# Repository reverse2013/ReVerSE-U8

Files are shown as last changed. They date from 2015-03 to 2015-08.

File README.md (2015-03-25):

# ReVerSE-U8
Development Kit

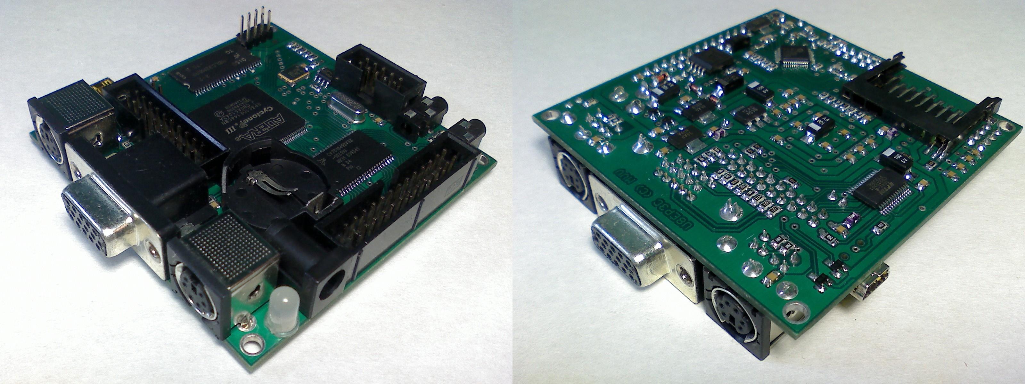
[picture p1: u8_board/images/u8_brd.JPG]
 
Платформа ориентированна на создание SoC систем на микросхеме программируемой логики ПЛИС. Отлично подходит для домашнего обучения и позволяет полностью воссоздать множество ретро-компьютеров.

Схема реализуемого устройства задается прошивкой, записываемой в статическую память микросхемы ПЛИС. Микросхема ПЛИС представляет собой массив логических элементов, таким образом, существует возможность исправления ошибок схемы, а также добавления новых устройств, с помощью перепрошивки ПЛИС (выполняемой средствами самого устройства, либо через USB-кабель). 

Системы-на-кристалле потребляют меньше энергии, стоят дешевле и работают надёжнее, чем наборы микросхем с той же функциональностью. В отличие от обычных цифровых микросхем, логика работы ПЛИС не определяется при изготовлении, а задаётся посредством программирования (проектирования).

Для программирования используются программаторы и отладочные среды, позволяющие задать желаемую структуру цифрового устройства в виде принципиальной электрической схемы или программы на специальных языках описания аппаратуры: Verilog, VHDL, AHDL и др. В конфигурации ПЛИС реализуются почти все компоненты компьютера. Вне ПЛИС находятся только оперативная память, аппаратные интерфейсы для подключения клавиатуры, мыши, монитора, и других устройств.

#### Спецификация:
- FPGA Altera EP3C10E144C8N (supports Cyclone III EP3C5)
- SDRAM 32MB x 8 bit (supports 8 MB/16 MB/32 MB x 8 bit)
- SRAM 512KB х 8 bit (supports 1024 КB)
- SPI FLASH 4 Mb (supports 1/4/16/64 Mb)
- Audio Codec VS1053b Ogg Vorbis/MP3/AAC/WMA/FLAC/MIDI 
- RTC PCF8583 + CR2032
- VGA 15-pin RGB(3:3:3)
- SD cart
- Connector 20-pin
- Connector 26-pin
- Connector 8-pin
- Audio in 3.5 mm 
- Audio out 3.5 mm
- miniUSB (USB-UART & CBUS-JTAG)
- JTAG (CBUS-JTAG)
- PS/2 keyboard/mouse
- PS/2 moude/keyboard
- Power DC +5V 500 mA
- PCB Size 75 х 75 mm

#### Вид платы:
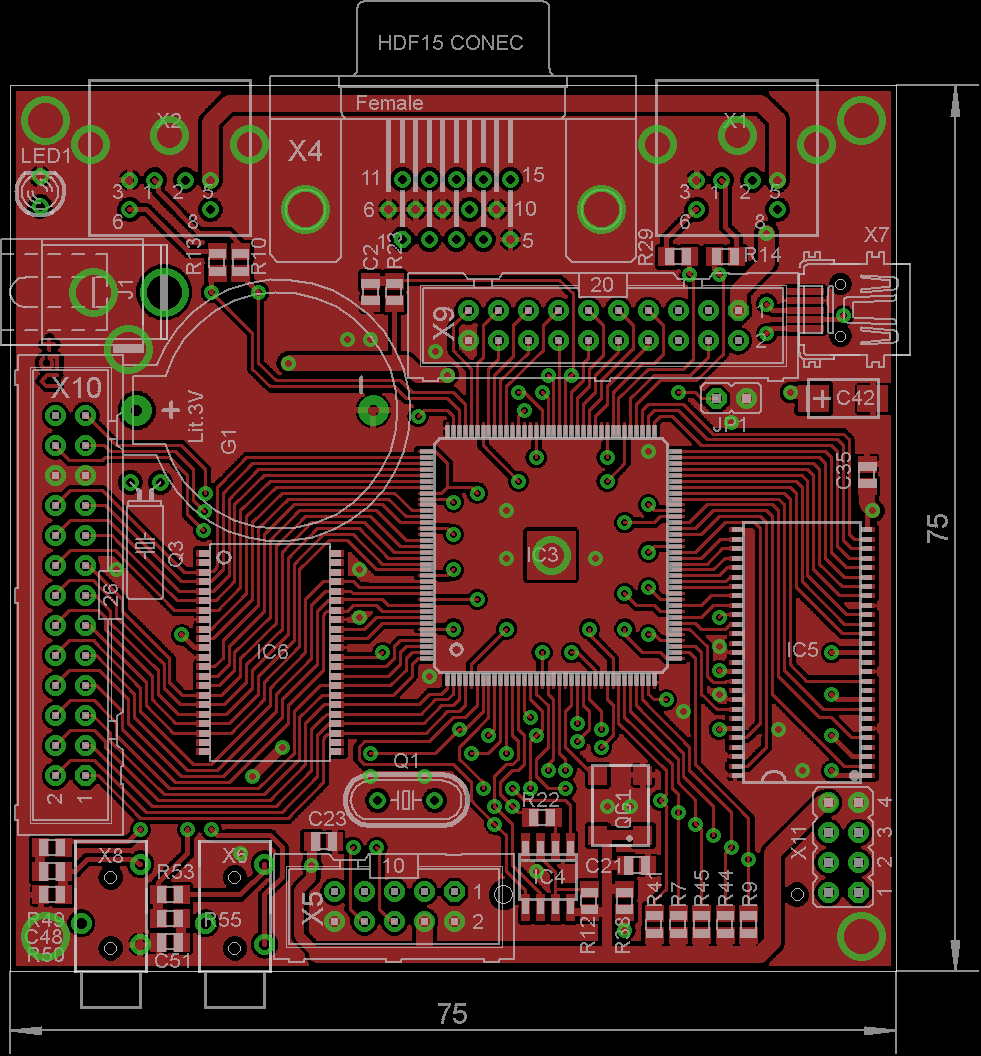
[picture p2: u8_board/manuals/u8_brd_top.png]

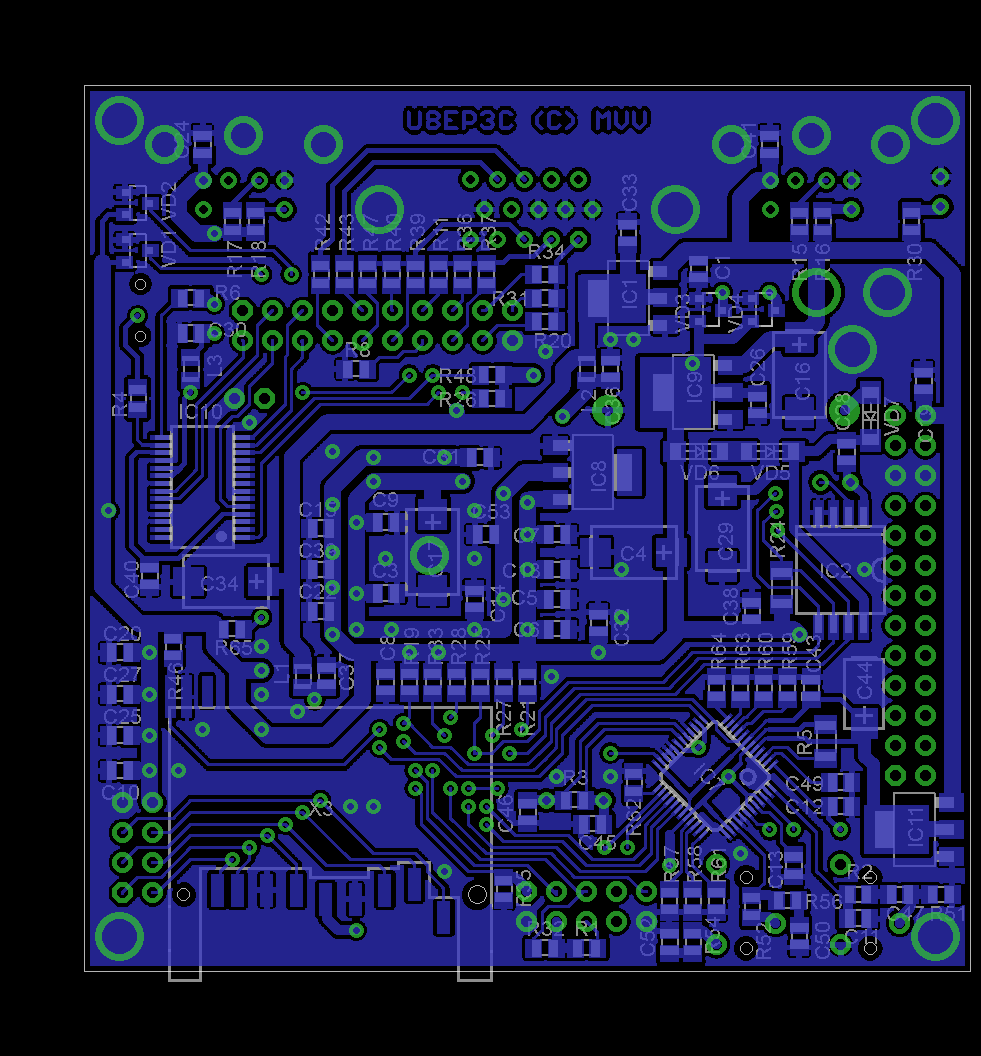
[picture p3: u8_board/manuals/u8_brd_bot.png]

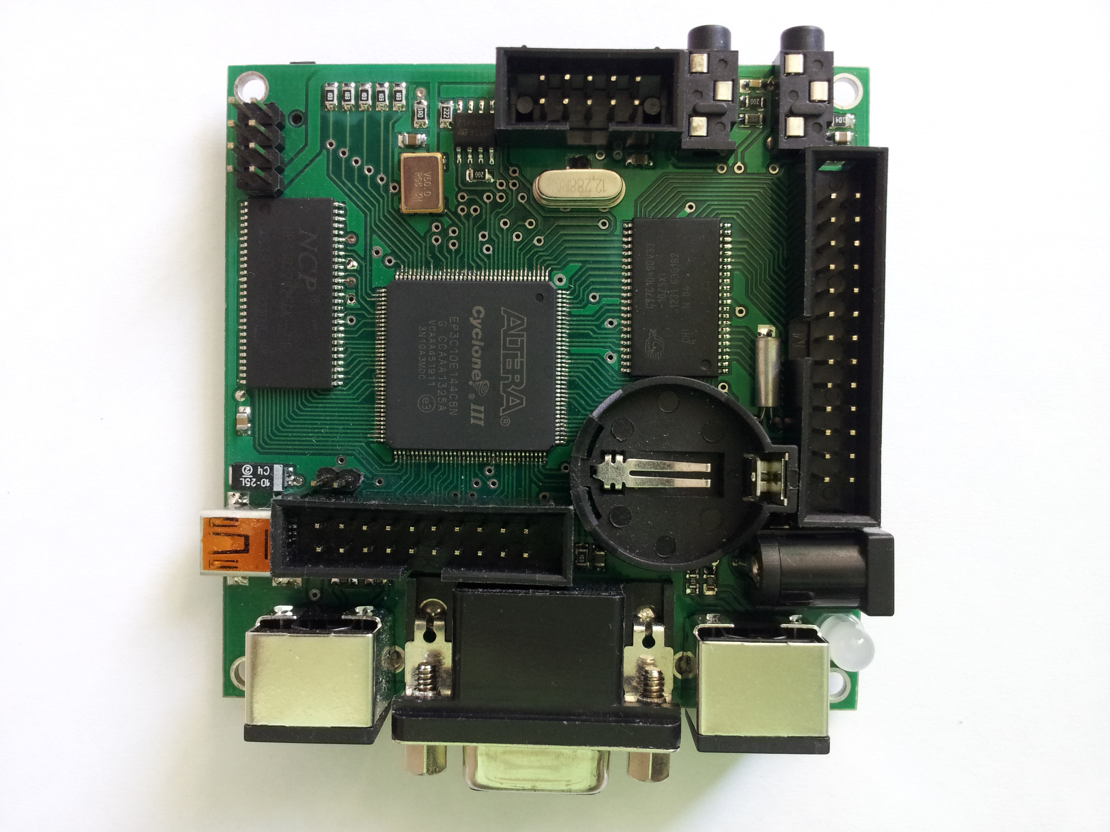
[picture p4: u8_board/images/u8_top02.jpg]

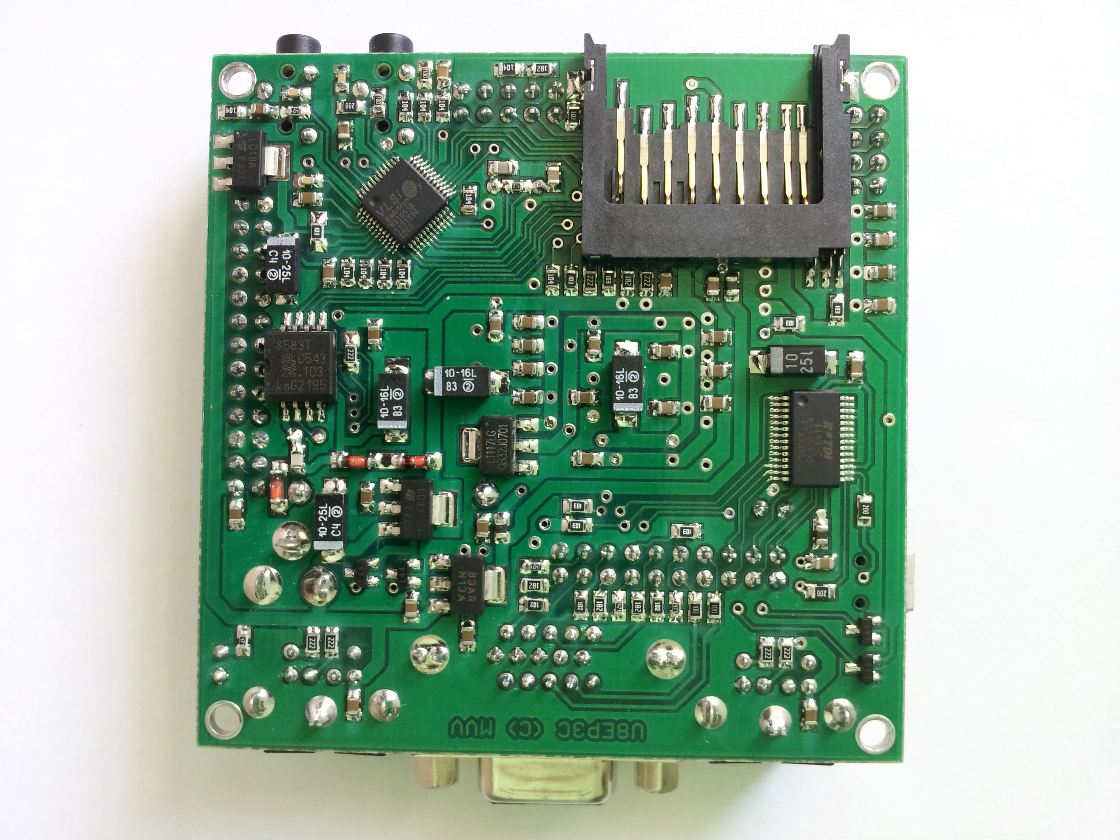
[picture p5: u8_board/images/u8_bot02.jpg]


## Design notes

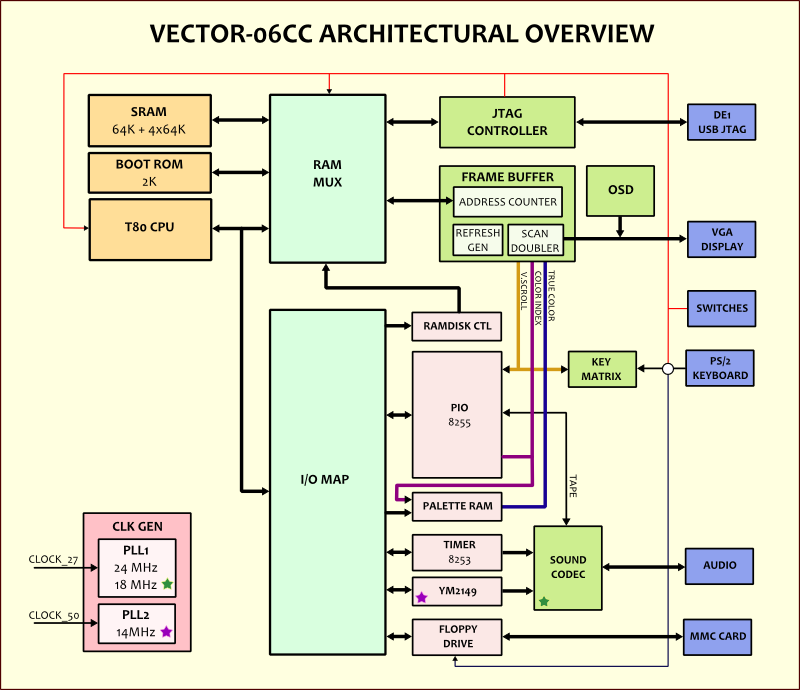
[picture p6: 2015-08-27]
u8_vector/doc/computer.png

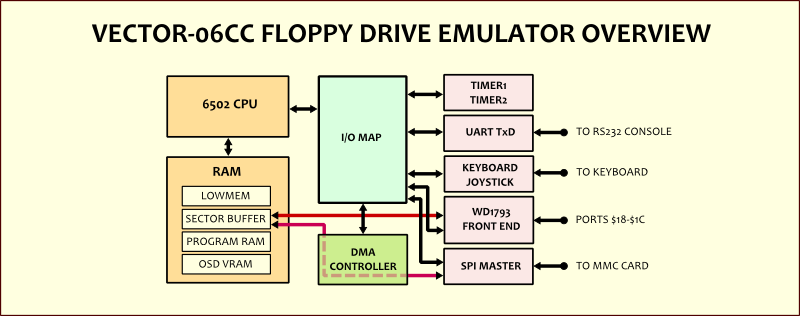
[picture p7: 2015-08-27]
u8_vector/doc/floppy.png

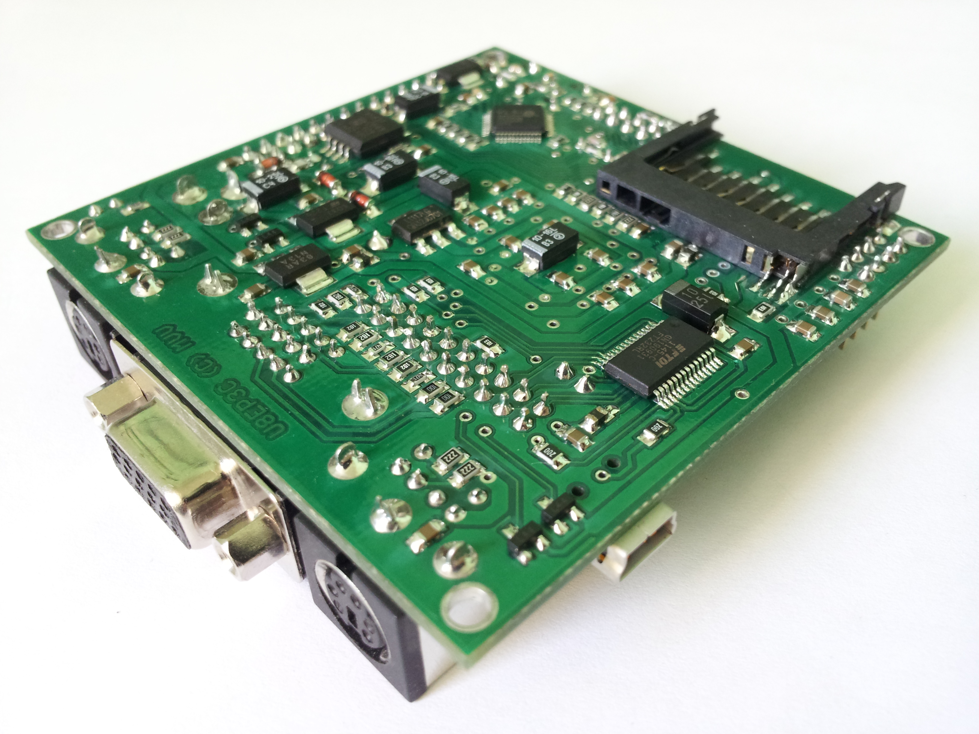
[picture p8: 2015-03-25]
u8_board/images/u8_bot01.jpg

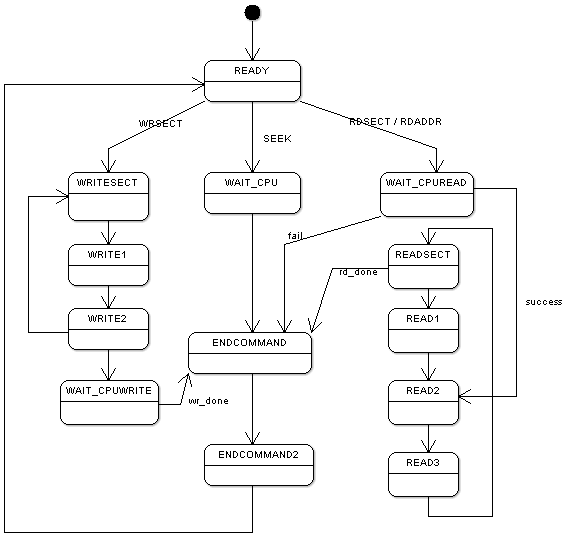
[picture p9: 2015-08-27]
u8_vector/doc/wd_statemachine.png

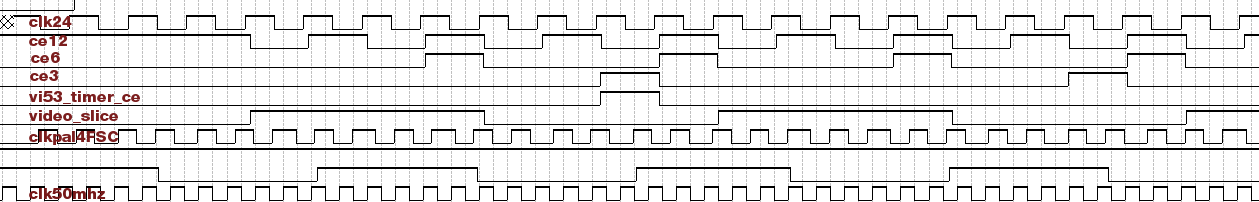
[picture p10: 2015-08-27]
u8_vector/doc/clocks-2.png

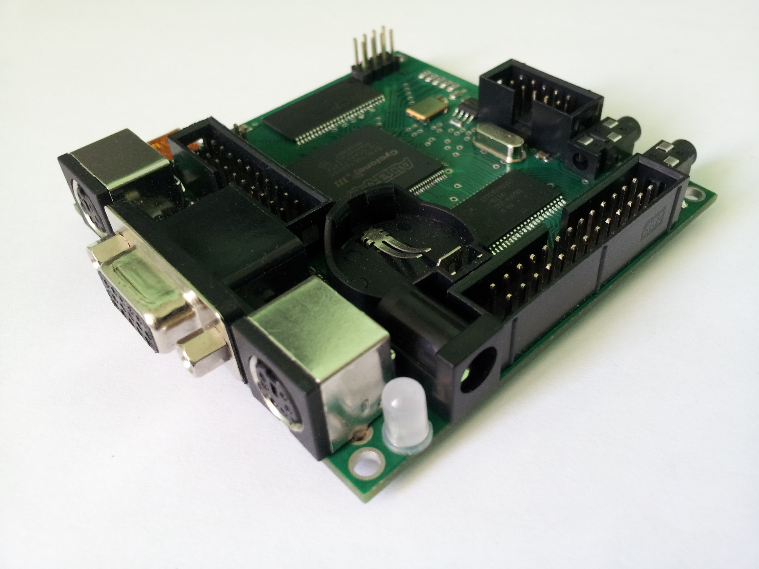
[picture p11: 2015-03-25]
u8_board/images/u8_top01.jpg

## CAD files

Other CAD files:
u8_speccy/boards/reverse_u9/syn/stp1.stp

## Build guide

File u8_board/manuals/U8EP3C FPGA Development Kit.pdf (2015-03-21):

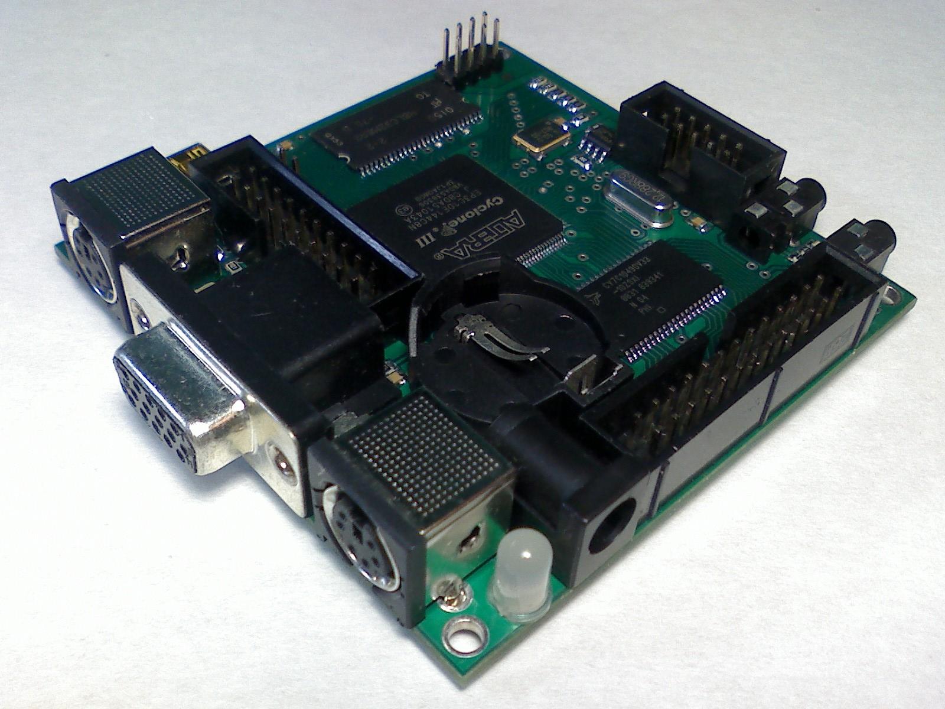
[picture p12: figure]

# U8EP3CFPGA Development Kit

# User Manual

## U8EP3C User Manual

# 1.1 Layout and Components

This chapter presents the features and design characteristics of the U8EP3C board.

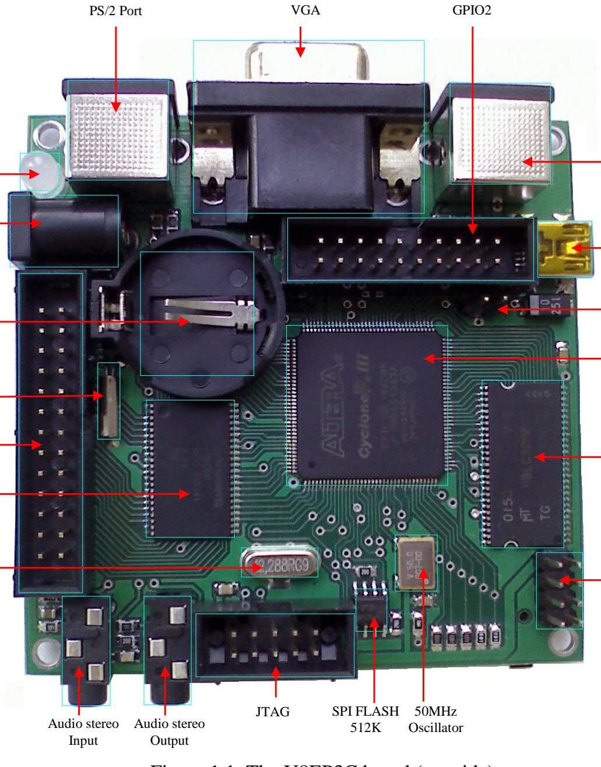
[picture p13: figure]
PS/2 Port; VGA; Audio stereo Input; JTAG; SPI FLASH; 50MHz Oscillator; GPIO2; Audio stereo Output

## Figure 1.1. The U8EP3C board (top side)

## A photograph of the U8EP3C board is shown in Figure 1.1-1.2. It depicts the layout of the

board and indicates the location of the connectors and key components.

## The following hardware is provided on the U8EP3C board:

## Altera Cyclone® III 3C10 FPGA device

## Altera Serial Configuration device – 512-Kbyte SPI Flash memory M25P40 (EPCS4)

## JTAG for programming and user API control; both and Active Serial (AS) programming

## modes are supported

## 32-Mbyte 8-bits SDRAM

## 512-Kbyte 8-bits SRAM memory

## SD Card socket

USB-UART

Power Led

Power Supply
5V DC

Reset/GPI
Battery CR2032

Oscillator
32.768KHz

SRAM
512K x 8 bit

GPIO3

SDRAM
32M x 8 bit

Cyclone III
EP3C10

PS/2 Port

Oscillator
12.288MHz

GPIO1

## 1 red power LED

## 50-MHz oscillator for clock sources

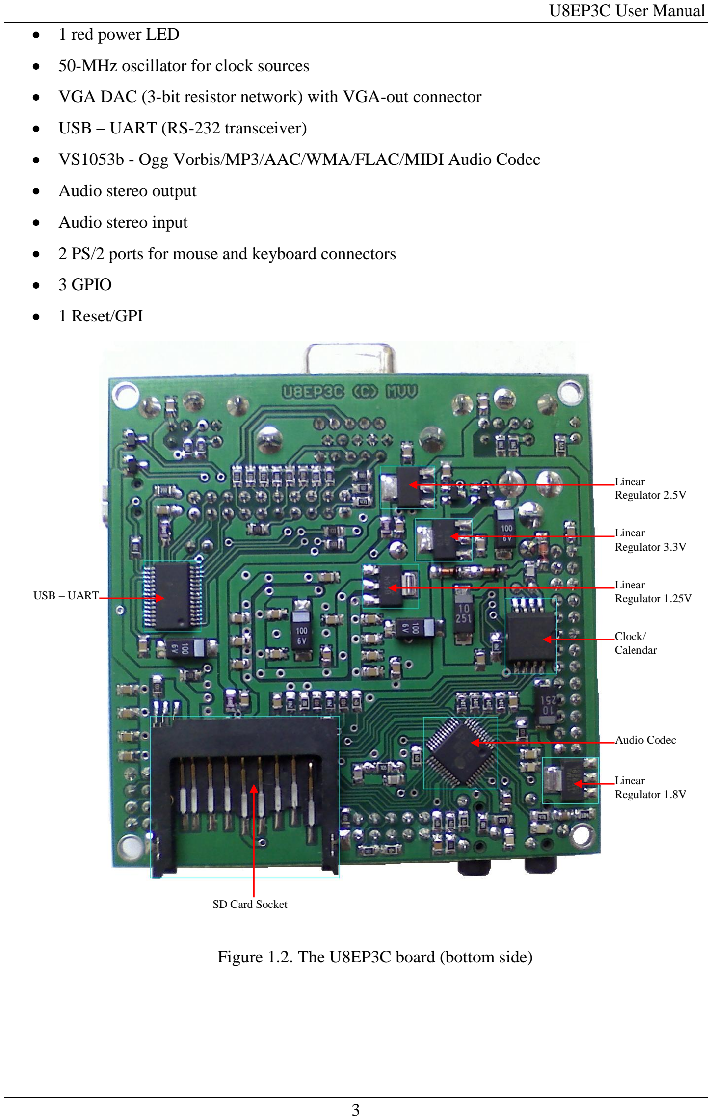
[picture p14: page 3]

## VGA DAC (3-bit resistor network) with VGA-out connector

## USB – UART (RS-232 transceiver)

## VS1053b - Ogg Vorbis/MP3/AAC/WMA/FLAC/MIDI Audio Codec

## Audio stereo output

## Audio stereo input

## 2 PS/2 ports for mouse and keyboard connectors

## 3 GPIO

## 1 Reset/GPI

## Figure 1.2. The U8EP3C board (bottom side)

USB – UART

Linear
Regulator 2.5V

Linear
Regulator 3.3V

Linear
Regulator 1.25V

SD Card Socket

Audio Codec

Clock/
Calendar

Linear
Regulator 1.8V

# Appendix 2.1 ByteBlasterMV Schematic

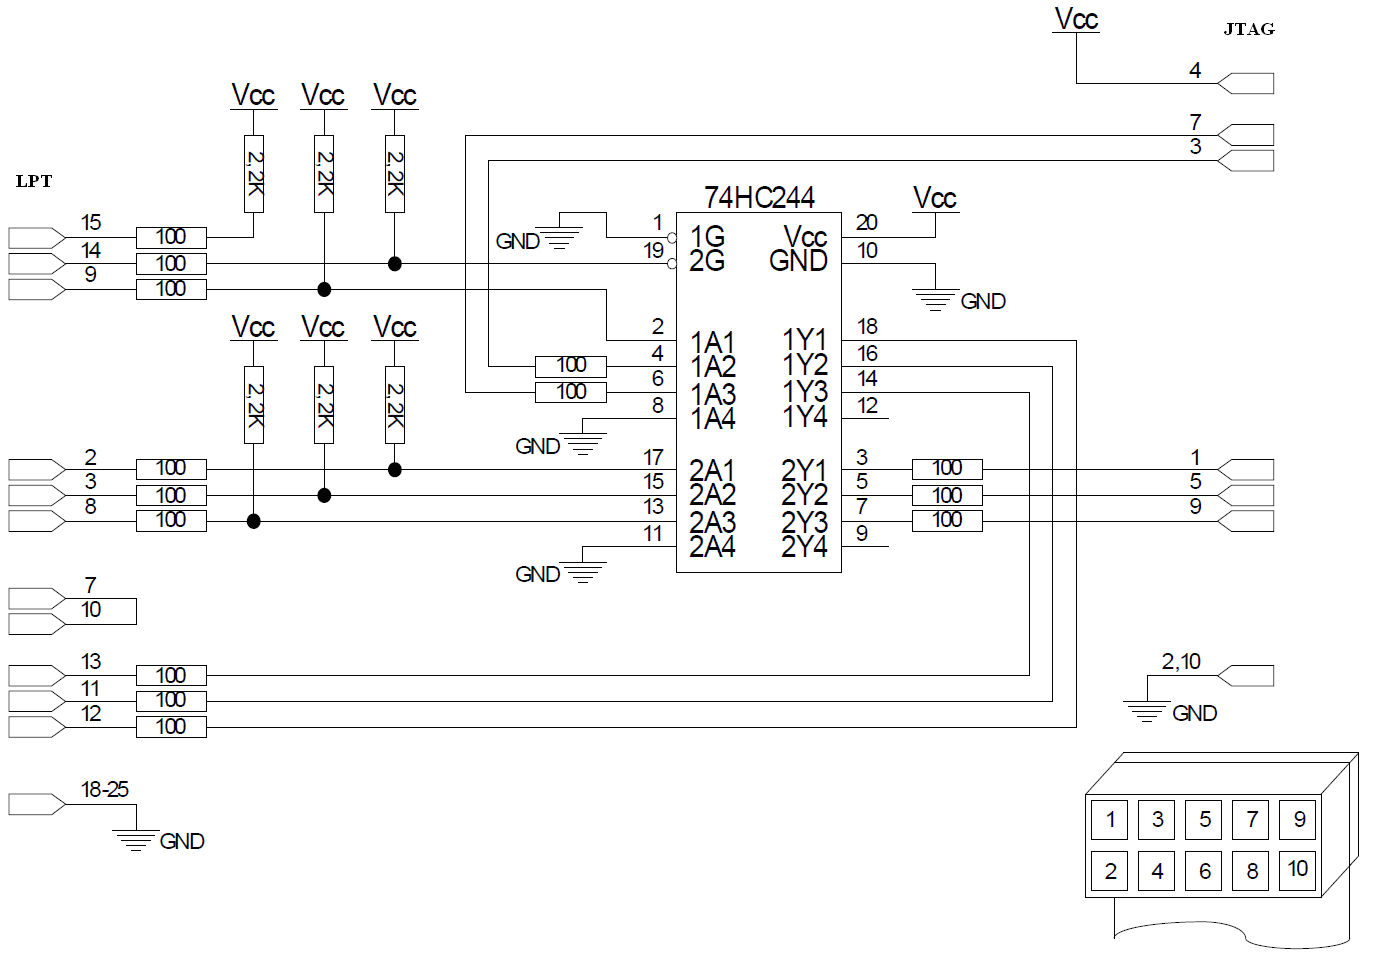
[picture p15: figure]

## ByteBlasterMV Female Plug’s Pin Names & Download Modes

Pin | PS Mode | JTAG Mode
Signal Name | Description | Signal Name | Description
1 | DCLK | Clock signal | TCK | Clock signal
2 | GND | Signal ground | GND | Signal ground
3 | CONF_DONE | Configuration control | TDO | Data from device
4 | VCC | Power supply | VCC | Power supply
5 | nCONFIG | Configuration control | TMS | JTAG state machine control
6 | - | No connect | - | No connect
7 | nSTATUS | Configuration status | - | No connect
8 | - | No connect | - | No connect
9 | DATA0 | Data to device | TDI | Data to device
10 | GND | Signal ground | GND | Signal ground

# Components

LED1 : LED3MM : LED (red) | C41 : 100nF : C0805 | R48 : 10K : R0805
Q1 : 12.288MHz : HC49/S | C42 : 4.7mF : CT6032 | R49 : 470R : R0805
Q3 : 32.768kHz : TC38H | C43 : 100nF : C0805 | R50 : 100K : R0805
QG1 : 50MHz : SM77H | C44 : 10mF : CT6032 | R51 : 100K : R0805
| C45 : 22pF : C0805 | R52 : 10R : R0805
G1 : CR2032HH : CR2032 | C46 : 22pF : C0805 | R53 : 10R : R0805
J1 : JACK-PLUG1 : SPC4078 | C47 : 1mF : C0805 | R54 : 10R : R0805
JP1 : Reset/GPI : Jumper 1-2 | C48 : 1mF : C0805 | R55 : 20R : R0805
| C49 : 100nF : C0805 | R56 : 20R : R0805
X1 : PS/2 Mouse : SSV-BC06 | C50 : 10nF : C0805 | R57 : 100K : R0805
X2 : PS/2 Keyboard : SSV-BC06 | C51 : 10nF : C0805 | R58 : 100K : R0805
X3 : FPS009-3000 : FPS009-3000 | C52 : 47nF : C0805 | R59 : 100K : R0805
X4 : VGA : HDF15H | C53 : 100nF : C0805 | R60 : 100K : R0805
X5 : ML10 : ML10 | | R61 : 100K : R0805
X6 : Audio Out : AUB-13 | VD1 : BAT54S : SOT23 | R62 : 100K : R0805
X7 : MINI-USB : 32005-201 | VD2 : BAT54S : SOT23 | R63 : 100K : R0805
X8 : Audio In : AUB-13 | VD3 : BAT54S : SOT23 | R64 : 100K : R0805
X9 : ML20 : ML20 | VD4 : BAT54S : SOT23 | R65 : 10K : R0805
X10 : ML26 : ML26 | VD5 : 1N4148 : SMA-DO214AC
X11 : JP4Q : JP4Q | VD6 : 1N4148 : SMA-DO214AC | Chips | Resistors
| VD7 : 1N4148 : SMA-DO214AC | PCF8583T : 1 | 1R : 1
IC1 : LM1117-2.5-0.8A : SOT223 | | EP3C10E144 : 1 | 10R : 3
IC2 : PCF8583T : SO8 | L1 : 10NH : I0805 | M25P40 : 1 | 20R : 5
IC3 : EP3C10E144 : EQFP144 | L2 : 10NH : I0805 | MT48LC32M8A2 : 1 | 120R : 6
IC4 : M25P40 : SOIC8 | L3 : 10NH : I0805 | CY7C1049DV33 : 1 | 470R : 6
IC5 : MT48LC32M8A2-TG : TSOP54-400 | | VS1053b : 1 | 1K : 4
IC6 : CY7C1049DV33T : TSOPII-Z44 | R1 : 100K : R0805 | FT232RL : 1 | 1K8 : 5
IC7 : VS1053b : LQFP48 | R2 : 470R : R0805 | Connectors | 2K4 : 8
IC8 : LM1117-1.2-0.8A : SOT223 | R3 : 1M : R0805 | SSV-BC06 : 2 | 10K : 14
IC9 : LM1117-3.3-0.8A : SOT223 | R4 : 20R : R0805 | CR2032HH : 1 | 100K : 12
IC10 : FT232RL : SSOP28 | R5 : 10K : R0805 | SPC4078 : 1 | 1M : 1
IC11 : LM1117-1.8-0.8A : SOT223 | R6 : 20R : R0805 | FPS009-3000 : 1 | Capacitors
| R7 : 10K : R0805 | HDF15H : 1 | 5pF : 1
C1 : 100nF : C0805 | R8 : 10K : R0805 | ML10 : 1 | 22pF : 2
C2 : 100nF : C0805 | R9 : 10K : R0805 | ML20 : 1 | 10nF : 4
C3 : 100nF : C0805 | R10 : 120R : R0805 | ML26 : 1 | 47nF : 1
C4 : 100mF/6V : CT6032 | R11 : 470R : R0805 | ML8 : 1 | 100nF : 35
C5 : 100nF : C0805 | R12 : 2K4 : R0805 | AUB-13 : 2 | 1mF : 3
C6 : 100nF : C0805 | R13 : 120R : R0805 | Mini-USB : 1 | 10mF/6V : 3
C7 : 100nF : C0805 | R14 : 120R : R0805 | Jumper 1-2 : 1 | 100mF/6V : 4
C8 : 100nF : C0805 | R15 : 2K4 : R0805 | Stabilizers | Oscillators
C9 : 100nF : C0805 | R16 : 2K4 : R0805 | LM1117-1.2-0.8A :1 | 32.768kHz : 1
C10 : 100nF : C0805 | R17 : 2K4 : R0805 | LM1117-2.5-0.8A :1 | 12.288MHz : 1
C11 : 10nF : C0805 | R18 : 2K4 : R0805 | LM1117-1.8-0.8A :1 | 50MHz : 1
C12 : 10nF : C0805 | R19 : 2K4 : R0805 | LM1117-3.3-0.8A :1 | Diode
C13 : 1mF : C0805 | R20 : 470R : R0805 | Inductances | BAT54SW : 4
C14 : 100nF : C0805 | R21 : 100K : R0805 | 10NH : 3 | 1N4148 : 3
C15 : 100nF : C0805 | R22 : 20R : R0805 | | LED 5mm : 1
C16 : 100mF/6V : CT6032 | R23 : 10K : R0805
C17 : 100mF/6V : CT6032 | R24 : 2K4 : R0805 | Notes:
C18 : 100nF : C0805 | R25 : 2K4 : R0805 | C42 : 4.7mF/6V <> 10mF/6V
C19 : 100nF : C0805 | R26 : 10K : R0805 | LED1 : LED3MM <> LED5MM (red)
C20 : 100nF : C0805 | R27 : 10K : R0805 | R30 : 470R <> 2K4
C21 : 100nF : C0805 | R28 : 10K : R0805 | IC3 : EP3C10E144 <> EP3C5E144
C22 : 100nF : C0805 | R29 : 120R : R0805 | IC4 : M25P40 <> EPCS4
C23 : 100nF : C0805 | R30 : 470R : R0805 | IC5 : MT48LC32M8A2 <> MT48LC64M8A2
C24 : 100nF : C0805 | R31 : 1K8 : R0805 | IC6 : CY7C1049DV33 <> CY7C1059DV33
C25 : 100nF : C0805 | R32 : 1K8 : R0805 | VD1..4 : BAT54SW <> BAT54S
C26 : 100nF : C0805 | R33 : 1K8 : R0805 | Packaging Marking:
C27 : 100nF : C0805 | R34 : 1K : R0805 | LM1117-1.2-0.8A = N03A/N03B
C28 : 5pF : C0805 | R35 : 1K : R0805 | LM1117-2.5-0.8A = N13A
C29 : 10mF : CT6032 | R36 : 1K8 : R0805 | LM1117-1.8-0.8A = N12A
C30 : 100nF : C0603 | R37 : 1K : R0805 | LM1117-3.3-0.8A = N05A/N05B
C31 : 100nF : C0805 | R38 : 1R : R0805
C32 : 100nF : C0805 | R39 : 1K8 : R0805
C33 : 100nF : C0805 | R40 : 1K : R0805
C34 : 100mF/6V : CT6032 | R41 : 10K : R0805
C35 : 100nF : C0805 | R42 : 120R : R0805
C36 : 100nF : C0805 | R43 : 120R : R0805
C37 : 100nF : C0805 | R44 : 10K : R0805
C38 : 100nF : C0805 | R45 : 10K : R0805
C39 : 100nF : C0805 | R46 : 10K : R0805
C40 : 100nF : C0805 | R47 : 470R : R0805

# Board Top View

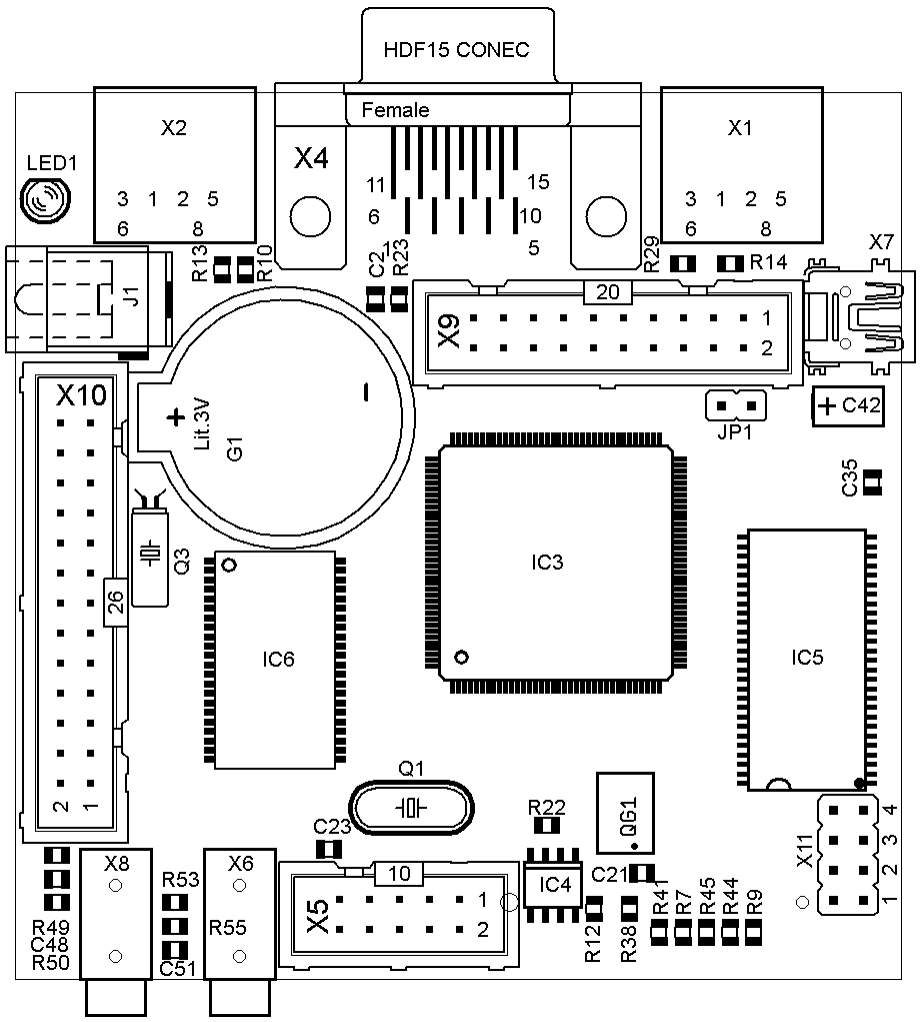
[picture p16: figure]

# Board Bottom View

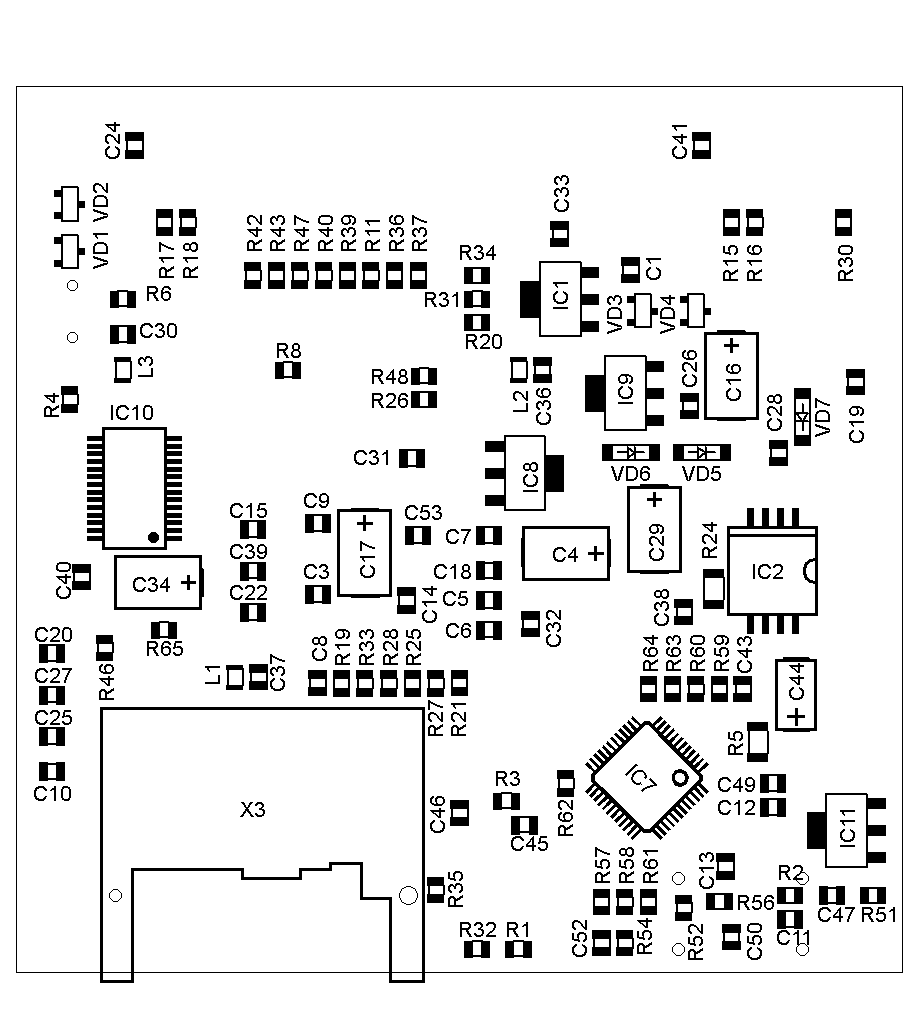
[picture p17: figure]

# Schematics

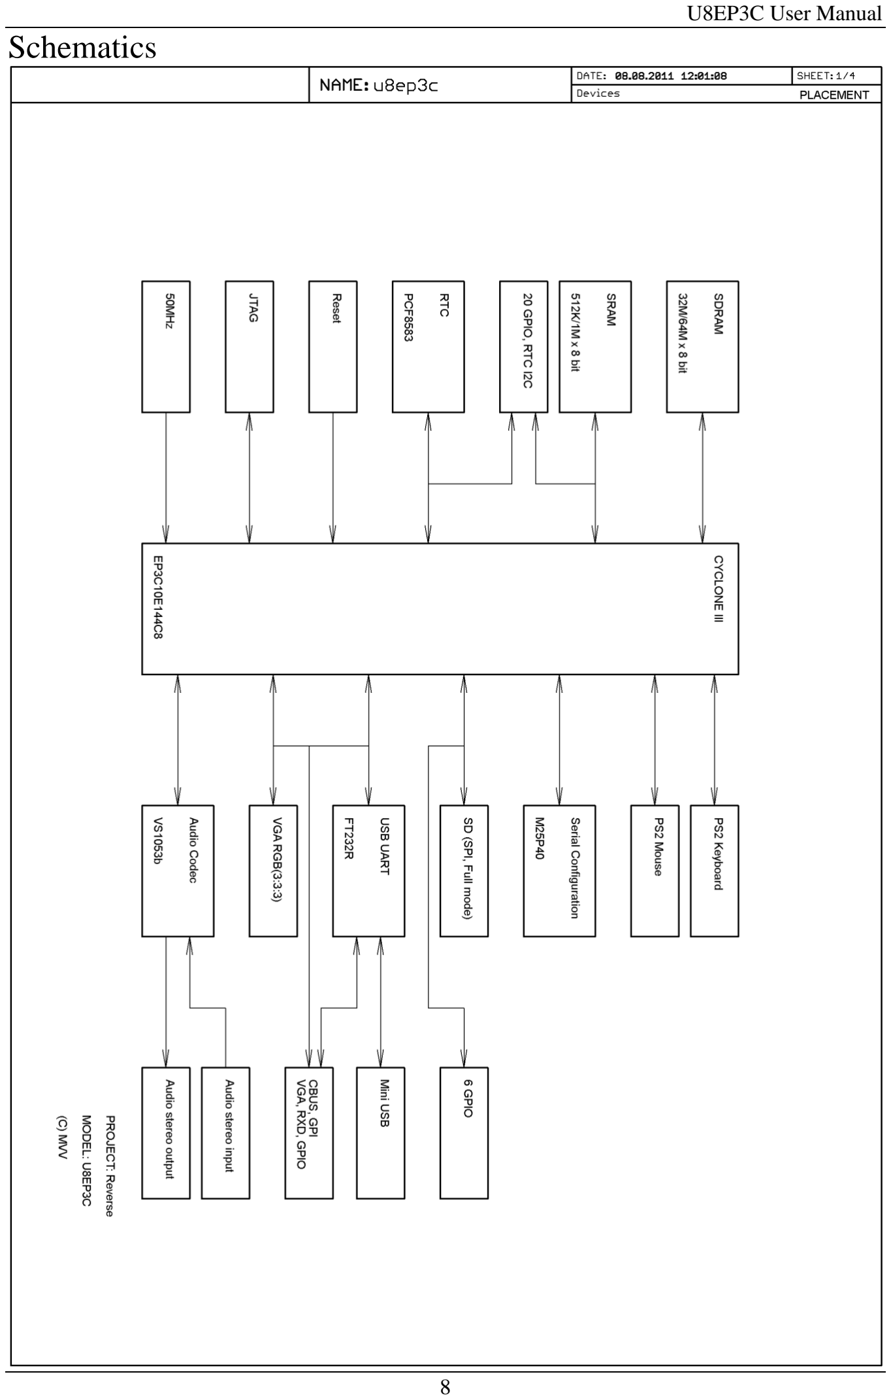
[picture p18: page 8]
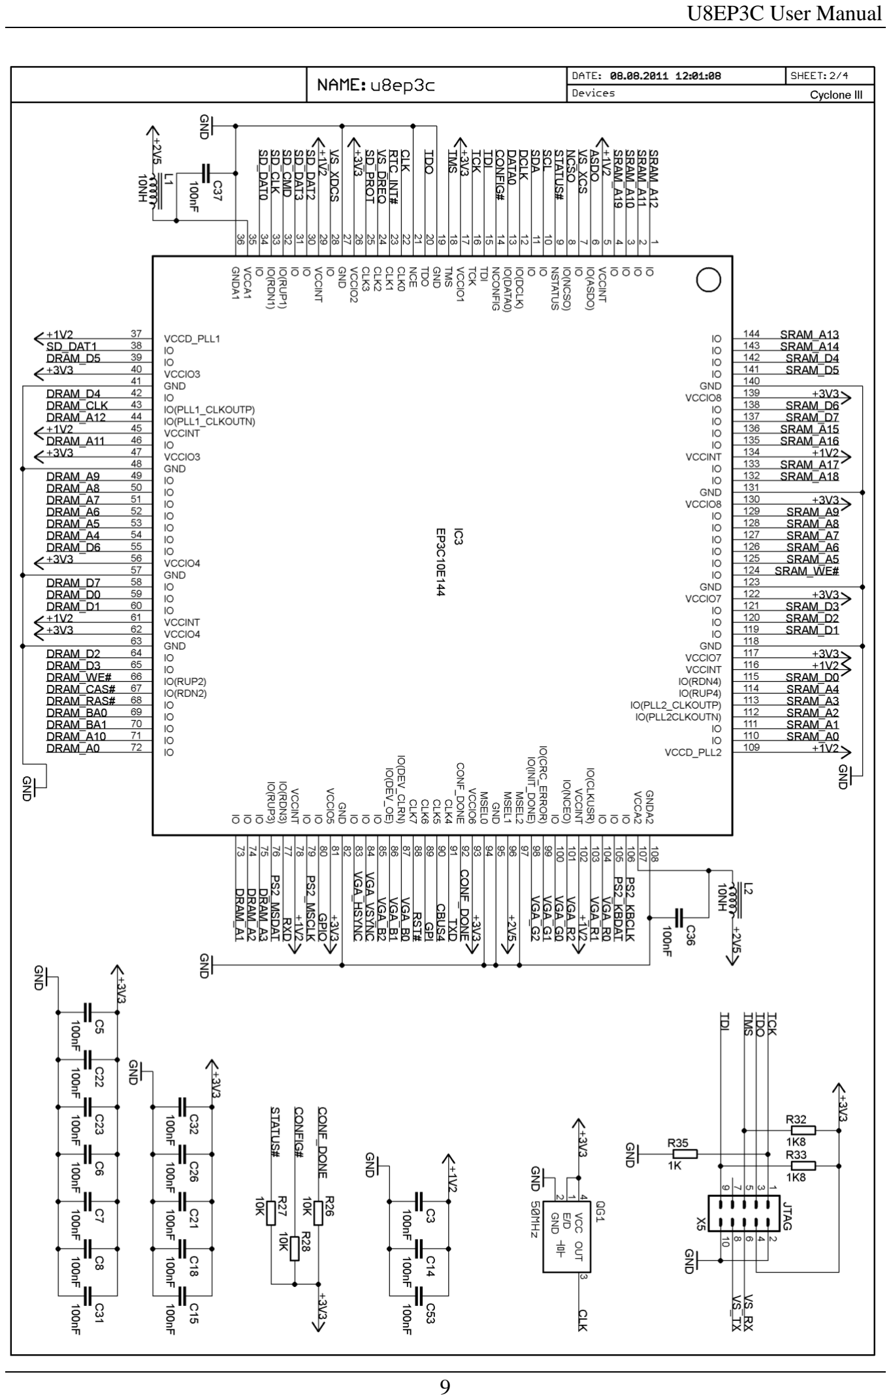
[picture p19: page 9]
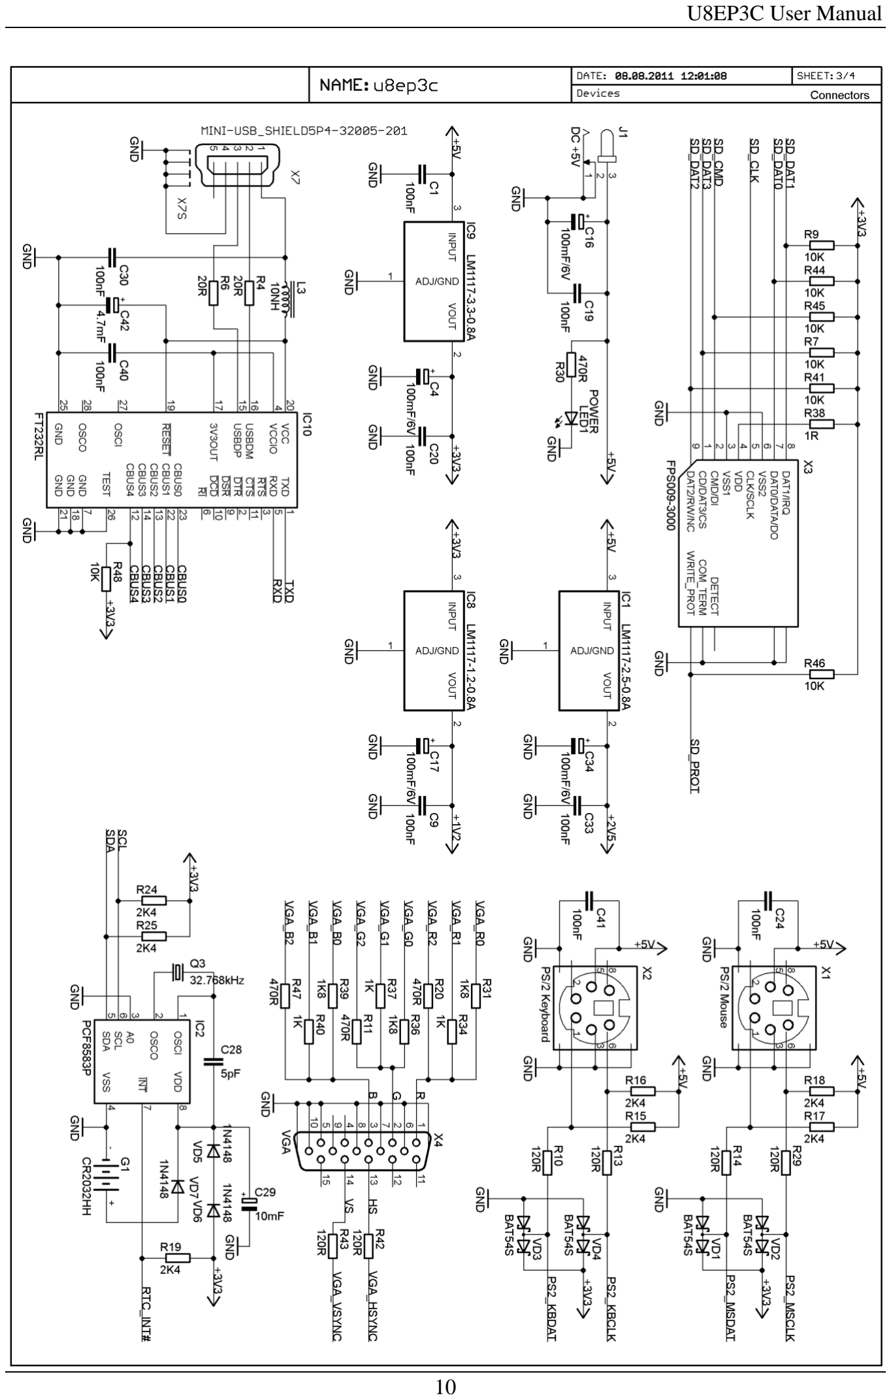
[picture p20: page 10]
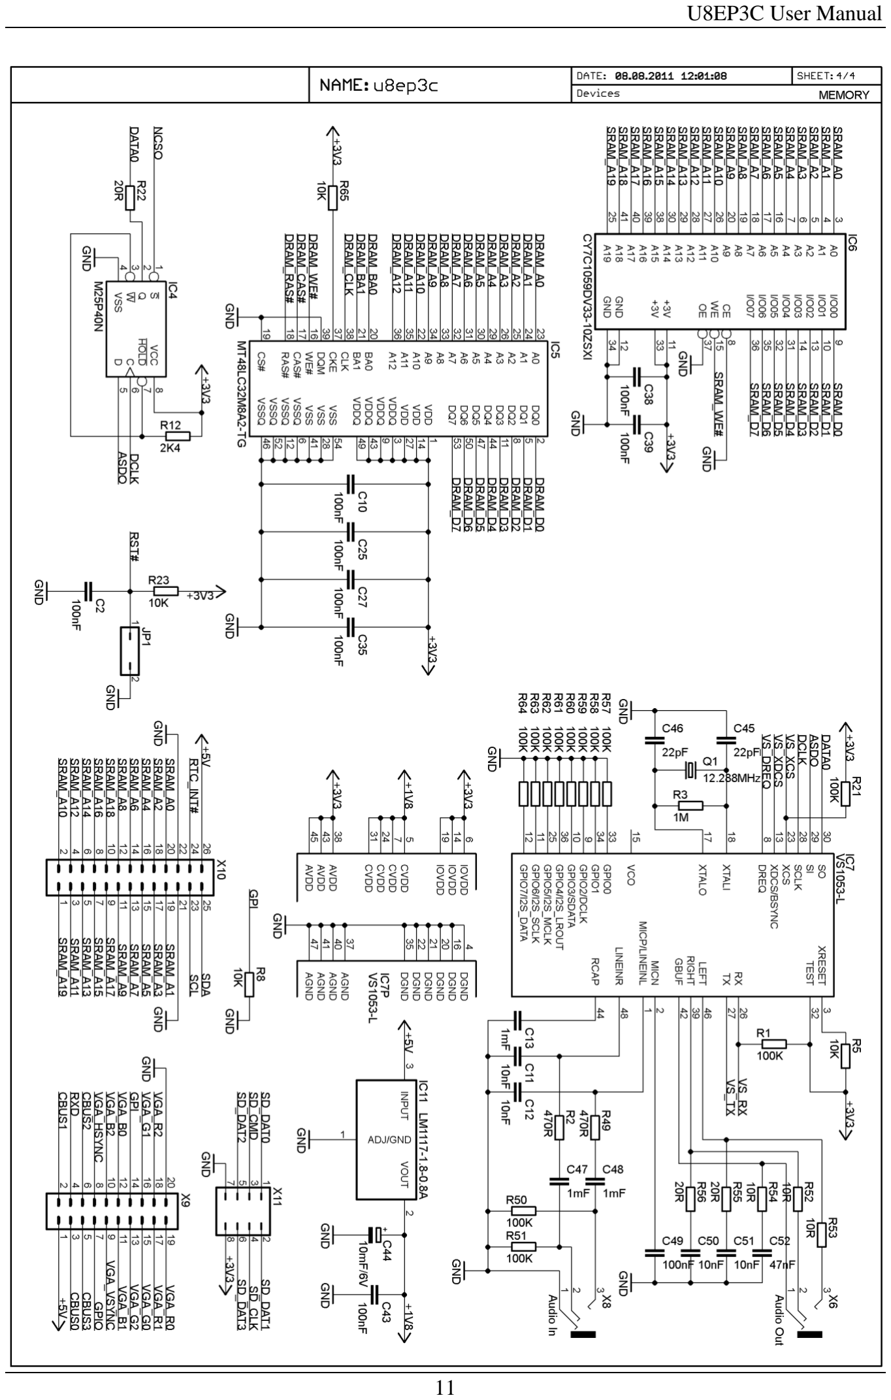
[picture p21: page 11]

# 2.2 Getting Help

## Here are the addresses where you can get help if you encounter problems:

## Forum:

## http://zx.pk.ru/showthread.php?t=13875

## http://zx.pk.ru/showthread.php?t=8993

## mvvproject@gmail.com

# 2.3 Revision History

Version | Change Log
V1.0 | Initial Version
V1.1 | U8EP3C Edition

# 2.4 Copyright Statement

Copyright © 2011 MVV.

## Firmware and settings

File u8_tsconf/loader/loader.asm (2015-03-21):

 		DEVICE	ZXSPECTRUM48
; -----------------------------------------------------------------[21.09.2014]
; ReVerSE-U8 Loader Version 0.2.6 By MVV
; -----------------------------------------------------------------------------
; V0.2.2	12.08.2014	первая версия
; V0.2.6	21.09.2014	RTC Setup

system_port	EQU #0001	; bit2 = 0:loader on, 1:loader off; bit1 = 0:sram<->cpu0, 1:sram<->gs;
pr_param	EQU #7f00
page3init 	EQU #7f05      	; RAM mem in  BANK1 (lowest  addr)
block_16k_cnt 	EQU #7f06
cursor_pos	EQU #7f07
buffer		EQU #8000

	org #0000
startprog:
	di               	; disable int
	ld sp,#7ffe	 	; stack - bank1:(exec code - bank0):destination 
	
	xor a
	ld bc,system_port
	out (c),a
	out (#fe),a		; цвет бордюра
	call cls		; очистка экрана
	ld hl,str1
	call print_str


	ld bc,#13af
	in a,(c)
	ld (page3init),a

	xor a
	LD (block_16k_cnt), A

	ld a,%00000001		; bit2 = 0:loader on, 1:loader off; bit1 = 0:sram<->cpu0, 1:sram<->gs; bit0 = 0:tda1543, 1:m25p40
	ld bc,#0001
	out (c),a





; 060000 GS 	32K

; -----------------------------------------------------------------------------
; SPI autoloader
; -----------------------------------------------------------------------------
	CALL spi_start
	LD D,%00000011	; Command = READ
	CALL spi_w

	LD D,#06	; Address = #060000
	CALL spi_w
	LD D,#00
	CALL spi_w
	LD D,#00
	CALL spi_w
	
	LD HL,#8000	; GS ROM 32K
SPI_LOADER1
	CALL spi_r
	LD (HL),A
	INC HL
	LD A,L
	OR H
	JR NZ,SPI_LOADER1
	
	ld a,%00000010	; bit2 = 0:loader on, 1:loader off; bit1 = 0:sram<->cpu0, 1:sram<->gs; bit0 = 0:tda1543, 1:m25p40
	ld bc,#0001
	out (c),a

	ld hl,str3
	call print_str

	ld hl,str2
	call print_str

; -----------------------------------------------------------------------------
; FAT16 loader
; -----------------------------------------------------------------------------
SD_LOADER
	CALL COM_SD
	DB 0
	CP 0
	JP NZ,ERR

	LD HL,#8000
	LD BC,#0000
	LD DE,#0000
	CALL COM_SD
	DB 2		; читаем MBR
	LD A,(#81C6)
	PUSH AF
	LD E,A
	LD D,0
	LD BC,#0000
	LD HL,#8000
	CALL COM_SD
	DB 2		; читаем BOOT RECORD на логическом разделе
	LD A,(#800E)
	LD C,A
	LD HL,(#8016)	; читаем размер FAT-каталога
	ADD HL,HL	; умножаем на два
	LD B,0
	ADD HL,BC	; прибавляем размер Reserved sectors
	LD C,#20
	ADD HL,BC	; прибавляем константу из расчета "два каталога FAT" и "размер сектора = 512 байт".
	POP AF
	LD C,A
	ADD HL,BC	; прибавляем смещение между физическими и логическими секторами

LOAD_16kb
	push hl        		; (sp)<--hl //load data addr (sector number)
	ex de,hl       		; de - сектрор для считывания данных 
	ld a,(block_16k_cnt)	; загружаем ячейку счетчика страниц в a
	ld bc,#13af
	out (c),a

	ld hl,#c000 		; destination memory : cpu0_a_bus(15 downto 14) = %11
				; de - начальный сектрор для считывания данных 
	ld bc,#0000
	ld a,#20            	; number of sectors : 512 * 32 = 16kb
	call COM_SD
	db 3		     	; читаем 16k
	cp 0
	jr nz,ERR

	pop hl		; в стеке был предыдущий стартовый номер сектора для считывания
	ld de,#0020  
	add hl,de 
	ld a,(block_16k_cnt)	; загружаем ячейку счетчика страниц в A
	inc a
	ld (block_16k_cnt),a
	cp 32
	jr c,LOAD_16kb

	ld hl,str3
	call print_str

	ld a,(page3init)	; RESTORE initial PAGE for Win3
	ld bc,#c000
	out (c),a
	jp RESET_LOADER
;------------------------------------------------------------------------------		
ERR
	ld hl,str_error
	call print_str
	di
	halt
stop
	jp stop
;==============================================================================		



RESET_LOADER
	ld hl,str4		; инициализация RTC
	call print_str

	call rtc_read
	ld hl,str_absent
	jr z,label1
	ld hl,str3
label1
	call print_str

	ld hl,str5
	call print_str

;------------------------------------------------------------------------------
; VS1053 Init
;------------------------------------------------------------------------------
vs_init
	ld a,%00000000          ; xcs=0 xdcs=0
	out (#05),a
	ld hl,table
	ld b,44
vs_init1
	ld d,(hl)
	call vs_rw
	inc hl
	djnz vs_init1
	ld a,%00100000          ; xcs=0 xdcs=1
	out (#05),a

	ld hl,str3		;завершено
	call print_str

	ld hl,str0		; any key
	call print_str

; Start System
	call anykey
	call mc14818a_init

	ld a,%00000110	; bit2 = 0:loader on, 1:loader off; bit1 = 0:sram<->cpu0, 1:sram<->gs; bit0 = 0:tda1543, 1:m25p40
	ld bc,#0001
	out (c),a

	ld sp,#ffff
	jp #0000	; запуск системы



; -----------------------------------------------------------------------------
; SD Driver
; -----------------------------------------------------------------------------
P_DATA		EQU #57
P_CONF		EQU #77

CMD_09		EQU #49		;SEND_CSD
CMD_10		EQU #4A		;SEND_CID
CMD_12		EQU #4C		;STOP_TRANSMISSION
CMD_17		EQU #51		;READ_SINGLE_BLOCK
CMD_18		EQU #52		;READ_MULTIPLE_BLOCK
CMD_24		EQU #58		;WRITE_BLOCK
CMD_25		EQU #59		;WRITE_MULTIPLE_BLOCK
CMD_55		EQU #77		;APP_CMD
CMD_58		EQU #7A		;READ_OCR
CMD_59		EQU #7B		;CRC_ON_OFF
ACMD_41		EQU #69		;SD_SEND_OP_COND

Sd_init		EQU 0
Sd__off		EQU 1
Rdsingl		EQU 2
Rdmulti		EQU 3
Wrsingl		EQU 4
Wrmulti		EQU 5

COM_SD	
	EX AF,AF'
	EX (SP),HL
	LD A,(HL)
	INC HL
	EX (SP),HL
	ADD A,A
	PUSH HL
	LD HL,TABLSDZ
	ADD A,L
	LD L,A
	LD A,H
	ADC A,0
	LD H,A
	LD A,(HL)
	INC HL
	LD H,(HL)
	LD L,A
	EX AF,AF'
	EX (SP),HL
	RET

TABLSDZ	
	DW SD_INIT	; 0 параметров не требует, на выходе A
			; смотри выше первые 2 значения
	DW SD__OFF	; 1 просто вырубает питание карты
	DW RDSINGL	; 2
	DW RDMULTI	; 3
	DW WRSINGL	; 4
	DW WRMULTI	; 5
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

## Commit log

2015-03-21 Нет коментария
    [TSconf.xls]
2015-03-25 Added GERBER
    [u8ep3c.drl, u8ep3c_Drills.xln, u8ep3c_Holes.xln]
2015-08-27 Added NES
    [nesdbg.sdf]
2015-08-27 Added Speccy
    [stp1.stp]
